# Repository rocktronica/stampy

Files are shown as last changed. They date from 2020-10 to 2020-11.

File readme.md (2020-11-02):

# stampy

OpenSCAD code for 3D-printed stamps, made especially for pottery.

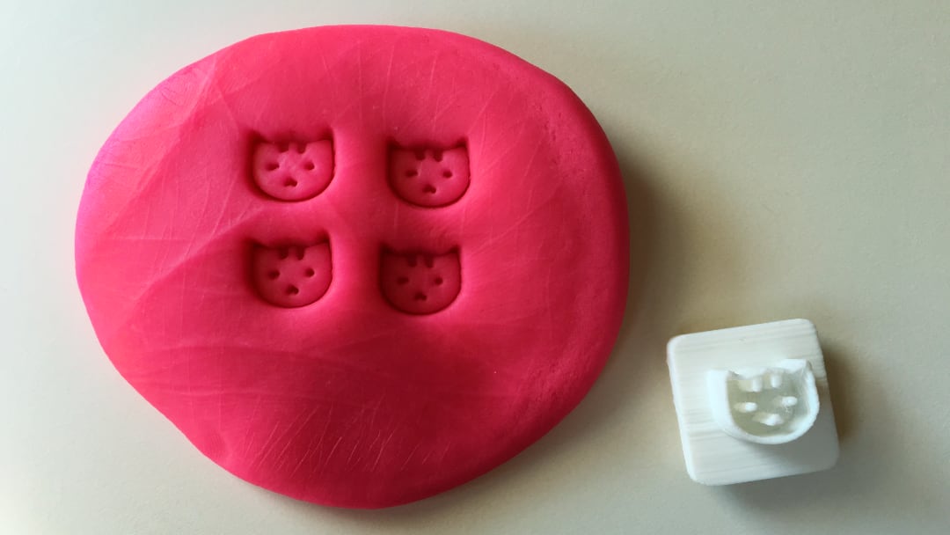
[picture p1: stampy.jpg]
stampy example on pink Play-Doh


## Images

Images are SVG files, flattened to work with OpenSCAD.

At small scales, keep the design simple and line widths consistent so no details get lost.

## Printing

Make sure `arrange_for_printer` in `stampy.scad` is `true`; this angles the stamps at 45 degrees, a Cool Trick to get higher resolution w/o additional suppots. Then slice at .1mm per layer.

It's helpful to print the stamps separately from their handles or anything else to prevent layer noise.

## License

MIT license.

Included `threads.scad` by [Dan Kirshner](https://dkprojects.net/openscad-threads/), GNU GPL license.

If you're using this for anything commercial, please switch the SVGs out -- I didn't design them.

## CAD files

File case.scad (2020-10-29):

use <donut.scad>;
use <threads.scad>;

module case(
    diameter = 90,
    floor_ceiling = 1.4,
    fillet = 5,
    wall = 4,

    thread_length = 4,
    thread_pitch = 2,
    tolerance = .1,
    clearance = .2,

    vertical_clearance = 2,

    engraving_depth = .8,

    relief_depth = 6,
    base_platform = 3,
    base_height = 3,
    base_size = 20,
    handle_height = 60,
    handle_diameter = 9,

    inner_wall = 2.4,

    z_gutter = 0,
    debug = true,
    bisect = true
) {
    height = 2 * (base_platform + base_height + relief_depth)
        + floor_ceiling * 2
        + vertical_clearance;

    e = .031;
    donut_fn = $preview ? 24 : 120;

    module outer() {
        if (debug) {
            cylinder(d = diameter, h = height);
        } else {
            hull() {
                for (z = [fillet, height - fillet]) {
                    translate([0, 0, z]) {
                        donut(diameter, fillet * 2, segments = donut_fn);
                    }
                }
            }
        }
    }

    module inner() {
        fillet = max(e, fillet - max(floor_ceiling, wall));

        if (debug) {
            translate([0, 0, floor_ceiling]) {
                cylinder(
                    d = diameter - wall * 2,
                    h = height - floor_ceiling * 2
                );
            }
        } else {
            hull() {
                for (z = [
                    floor_ceiling + fillet / 2,
                    height - fillet / 2 - floor_ceiling + e
                ]) {
                    translate([0, 0, z]) {
                        donut(
                            diameter - wall * 2,
                            fillet,
                            segments = donut_fn
                        );
                    }
                }
            }
        }
    }

    module threads(cavity = true) {
        bleed = tolerance + clearance;

        metric_thread(
            pitch = thread_pitch,
            diameter = diameter - wall * .8 + (cavity ? bleed * 3 : bleed * -2),
            length = thread_length,
            internal = !cavity,
            leadin = cavity ? 0 : 1,
            n_starts = 6
        );
    }

    module holders() {
        module handle_holder(
            fit_clearance = -.05, // intentionally tight
            width = wall * 3,
            end_gutter = wall
        ) {
            for (x = [
                handle_height / -2 + end_gutter,
                handle_height / 2 - width - end_gutter
            ]) {
                for (y = [
                    handle_diameter / -2 - inner_wall - fit_clearance,
                    handle_diameter / 2 + fit_clearance
                ]) {
                    translate([x, y, 0]) {
                        cube([width, inner_wall, handle_diameter]);
                    }
                }
            }

            % translate([
                handle_height / -2,
                0,
                handle_diameter / 2
            ]) rotate([0, 90, 0]) {
                cylinder(d = handle_diameter, h = handle_height);
            }
        }

        module base_holder(
            fit_clearance = .05
        ) {
            xy_overlap = base_size / 3;
            z_overlap = 2;

            translate([
                base_size / -2 - fit_clearance,
                base_size / -2 - fit_clearance,
                0
            ]) {
                a = -inner_wall;
                b = base_size - xy_overlap + fit_clearance * 2;

                full_height = base_height + base_platform + relief_depth;

                difference() {
                    union() {
                        for (p = [[a,a], [b,b]]) {
                            translate([p.x, p.y, 0]) {
                                cube([
                                    inner_wall + xy_overlap,
                                    inner_wall + xy_overlap,
                                    base_height + base_platform + z_overlap
                                ]);
                            }
                        }
                    }

                    translate([0, 0, -e]) {
                        cube([
                            base_size + fit_clearance * 2,
                            base_size + fit_clearance * 2,
                            full_height + e * 2
                        ]);
                    }
                }

                % translate([fit_clearance, fit_clearance, 0]) {
                    cube([
                        base_size,
                        base_size,
                        full_height + e
                    ]);
                }
            }
        }

        gutter = 4;
        y_plot = base_size / 2 + clearance + inner_wall
            + handle_diameter / 2 + inner_wall
            + gutter;

        for (y = [-y_plot, y_plot]) {
            translate([0, y, 0]) {
                base_holder();
            }
        }

        handle_holder();
    }

    module engraving(
        svg_filename = "bee-edit.svg",
        svg_width = 12.62,
        svg_length = 12.647,
        z = 0
    ) {
        scale = (diameter / 2) / max(svg_width, svg_length);

        translate([svg_width * scale / -2, svg_length * scale / -2, z]) {
            linear_extrude(engraving_depth + e) {
                offset(delta = tolerance) {
                    resize([
                        svg_width * scale,
                        svg_length * scale
                    ]) {
                        import(svg_filename);
                    }
                }
            }
        }
    }

    module gripper_cavities(count = 24, width = 6, length = 1.2) {
        for (i = [0 : count - 1]) {
            rotate([0, 0, (i / count) * 360]) {
                translate([width / -2, diameter / 2 - length, -e]) {
                    * % cube([width, length + e, height / 2 + e * 2]);
                }

                translate([0, diameter / 2, -e]) {
                    scale([width / length, 1, 1]) {
                        cylinder(
                            d = length,
                            h = height + e * 2,
                            $fn = 12
                        );
                    }
                }
            }
        }
    }

    module bottom() {
        difference() {
            union() {
                intersection() {
                    outer();
                    cylinder(d = diameter + e * 2, h = height / 2, $fn = donut_fn);
                }
                translate([0, 0, height / 2 -e]) {
                    threads(cavity = false);
                }
            }

            inner();

            engraving(
                "bee-edit.svg", 12.62, 12.647,
                z = -e
            );

            gripper_cavities();
        }

        translate([0, 0, floor_ceiling - e]) {
            # holders();
        }
    }

    module top() {
        difference() {
            intersection() {
                outer();
                translate([0, 0, height / 2]) {
                    cylinder(d = diameter + e * 2, h = height / 2, $fn = donut_fn);
                }
            }

            inner();

            translate([0, 0, height / 2 -e]) {
                threads(cavity = true);
            }

            engraving(
                "cat-smaller-mouth-edit.svg", 12.142, 10.028,
                z = height - engraving_depth
            );

            gripper_cavities();
        }

        translate([0, 0, height - floor_ceiling + e]) {
            mirror([0, 0, 1]) {
                # holders();
            }
        }
    }

    intersection() {
        union() {
            translate([0, 0, z_gutter]) top();
            bottom();
        }

        if (bisect) {
            translate([-diameter, 0, 0]) cube([diameter * 2, diameter, diameter]);
        }
    }
}

case(z_gutter = 5);

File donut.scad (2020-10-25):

module donut(
    diameter,
    thickness,
    segments = 24,
    starting_angle = 0,
    coverage = 360
) {
    e = .001;

    segments = max(1, round(segments * (coverage / 360)));

    module segment(angle = 0) {
        rotate([0, 0, -angle]) {
            translate([e / -2, diameter / 2 - thickness / 2, 0]) {
                rotate([0, 90, 0]) {
                    cylinder(d = thickness, h = e);
                }
            }
        }
    }

    for (i = [0 : segments - 1]) {
        hull() {
            segment(starting_angle + i * (coverage / segments));
            segment(starting_angle + (i + 1) * (coverage / segments));
        }
    }
}

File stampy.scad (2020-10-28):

use <donut.scad>;
use <threads.scad>;

module cat_stamp(
    svg_filename = "bee-edit.svg",
    svg_width = 12.62,
    svg_length = 12.647,

    relief_depth = 6,
    relief_bleed = -.1,
    relief_scale = 1,
    relief_rotation = 0,

    base_width = undef,
    base_length = undef,
    base_height = 3,
    base_radius = 2,
    base_rim = 2,
    base_platform = 3,

    handle_diameter = undef,
    handle_height = 60,

    tolerance = .2,

    include_handle = true,
    arrange_for_printer = true,

    $fn = 12
) {
    base_width = base_width != undef
        ? base_width
        : svg_width * relief_scale + base_rim * 2;
    base_length = base_length != undef
        ? base_length
        : svg_length * relief_scale + base_rim * 2;

    handle_diameter = handle_diameter != undef
        ? handle_diameter
        : base_height + relief_depth;
    handle_cavity_depth = base_height + base_platform - .6;

    e = .031;

    module threads(
        cavity = true,
        bleed = 0,
        cavity_chamfer = .4
    ) {
        metric_thread(
            diameter = handle_diameter + bleed * 2,
            length = cavity ? handle_cavity_depth + e * 2 : handle_cavity_depth,
            internal = !cavity,
            leadin = cavity ? 0 : 1
        );

        if (cavity) {
            cylinder(
                d1 = handle_diameter + bleed * 2 + cavity_chamfer * 2,
                d2 = handle_diameter + bleed * 2,
                h = cavity_chamfer,
                $fn = 50
            );
        }
    }

    module relief(relief_bleed = 0) {
        translate([
            base_width / 2,
            base_length / 2,
            base_height + base_platform - e
        ]) {
            mirror([1, 0, 0]) {
                rotate([0, 0, relief_rotation]) {
                    translate([
                        (svg_width * relief_scale) / -2,
                        (svg_length * relief_scale) / -2,
                        0
                    ]) {
                        linear_extrude(relief_depth + e) {
                            offset(delta = relief_bleed) {
                                resize([
                                    svg_width * relief_scale,
                                    svg_length * relief_scale
                                ]) {
                                    import(svg_filename);
                                }
                            }
                        }
                    }
                }
            }
        }
    }

    module base() {
        difference() {
            hull() {
                for (x = [
                    base_radius + base_height,
                    base_width - base_radius - base_height
                ]) {
                    for (y = [
                        base_radius + base_height,
                        base_length - base_radius - base_height
                    ]) {
                        translate([x, y, 0]) {
                            cylinder(
                                r = base_radius,
                                h = e
                            );
                        }
                    }
                }

                for (x = [base_radius, base_width - base_radius]) {
                    for (y = [base_radius, base_length - base_radius]) {
                        for (z = [base_height, base_height + base_platform]) {
                            translate([x, y, z - e]) {
                                cylinder(
                                    r = base_radius,
                                    h = e
                                );
                            }
                        }
                    }
                }
            }

            translate([base_width / 2, base_length / 2, -e]) {
                threads(cavity = true, bleed = tolerance);
            }
        }
    }

    module handle(
        gutter = 2,
        fillet = 2,
        $fn = 24
    ) {
        y = sqrt(pow(base_length - base_height * 2, 2) / 2)
            + handle_diameter / 2
            + gutter;

        position = arrange_for_printer
            ? [base_width / 2, y, 0]
            : [base_width / 2, base_length / 2, -handle_height];

        translate(position) {
            hull() {
                donut(handle_diameter, fillet * 2, segments = $fn);

                translate([0, 0, handle_height - e]) {
                    cylinder(d = handle_diameter, h = e);
                }
            }

            translate([0, 0, handle_height]) {
                threads(cavity = false);
            }
        }
    }

    if (include_handle) {
        handle();
    }

    rotate([arrange_for_printer ? 45 : 0, 0, 0]) {
        translate([0, arrange_for_printer ? -base_height : 0, 0]) {
            base();
            # relief(relief_bleed);
        }
    }
}

module output(
    svgs = [
        // svg_filename, svg_width, svg_length
        ["bee-edit.svg", 12.62, 12.647],
        ["cat-smaller-mouth-edit.svg", 12.142, 10.028],
    ],
    rotations = [0, 90],
    plot = 22
) {
    for (i = [0 : len(svgs) - 1]) {
        svg = svgs[i];

        for (ii = [0 : len(rotations) - 1]) {
            translate([plot * i * 2 + plot * ii, 0, 0]) {
                cat_stamp(
                    svg_filename = svg[0],
                    svg_width = svg[1],
                    svg_length = svg[2],

                    relief_rotation = rotations[ii],

                    base_width = 20,
                    base_length = 20,

                    handle_diameter = 9,

                    include_handle = true,
                    arrange_for_printer = true
                );
            }
        }
    }
}

output();

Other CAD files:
threads.scad

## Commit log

2020-10-18 Add proof of concept
    [cat-stamp.scad]
2020-10-18 Test bleeds
    [cat-stamp.scad]
2020-10-18 Enable scaling
    [cat-stamp.scad]
2020-10-19 Test scales
    [cat-stamp.scad]
2020-10-19 Enable rounded base corners
    OUCH! too sharp
    [cat-stamp.scad]
2020-10-19 Chamfer sides for DFM
    Printing at 45deg angle = higher res
    And ditch support for 0 radius
    [cat-stamp.scad]
2020-10-19 Tidy params
    [cat-stamp.scad]
2020-10-19 Codify good scale+bleed values
    [cat-stamp.scad, utils.scad]
2020-10-20 Add handle
    [cat-stamp.scad, threads.scad]
2020-10-20 Match handle diameter and base+relief height
    This will make casing them nicer
    [cat-stamp.scad]
2020-10-25 Stub cute lil case
    [case.scad, donut.scad]
2020-10-25 Try new bees and cat head designs
    [cat-stamp.scad]
2020-10-26 Deter base imprint with deeper relief
    [cat-stamp.scad]
2020-10-26 Try bee SVG w/ bigger mouth
    [cat-stamp.scad]
2020-10-26 STUB lil holders in case
    [case.scad]
2020-10-28 Allow arbitrary base and handle dimensions
    [cat-stamp.scad]
2020-10-28 Parameterize svg_ stuff
    And standardize known-good relief_bleed
    And prep output() for multiple SVGs
    [cat-stamp.scad, utils.scad]
2020-10-28 Add new cat design
    [cat-stamp.scad]
2020-10-28 Try rotating for less sad cat eyes?
    [cat-stamp.scad]
2020-10-28 "Platform" base to make its edges less sharp
    [cat-stamp.scad]
2020-10-28 Make everything better
    and hopefully easier to work w/
    [cat-stamp.scad]
2020-10-28 Refine case
    [case.scad]
2020-10-28 Fillet handle
    and make lonnggger
    [cat-stamp.scad]
2020-10-29 Tighten case holder fits, fix height
    [case.scad]
2020-10-29 Decouple fit clearances
    [case.scad]
2020-10-29 Refine case some more
    * Reduce floor/ceilings
    * Loosen threads -- last print was impossible to open if closed all the way!
    * Fix incorrect height from base_height
    * Loosen base holders and fix their height too
    * Add lil gripper cavities
    [case.scad]
